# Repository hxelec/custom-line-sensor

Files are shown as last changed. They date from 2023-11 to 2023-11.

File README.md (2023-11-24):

# custom-line-sensor
A simple design for a custom line sensing array, using the well-known QRE1113GR reflective sensor, which is seen in most line followers (including crazy fast PID ones). The same design is also seen in the QTR series from Pololu.
Full tutorial is documented on my YouTube channel: https://www.youtube.com/watch?v=jIgIj2hZbxc
Notes: 
You really only need the QRE1113GR itself, and two resistors, however, I decided to add two decoupling capacitors for more stable signals. That makes the entire project just 18 parts, which is pretty simple.
Also, the tutorial PCB layout isn't the exact same as the one that I actually printed and used, for recording purposes. (It still works the exact same)
Nevertheless, the design files of the one I actually sent off to be manufactured are in this repository.

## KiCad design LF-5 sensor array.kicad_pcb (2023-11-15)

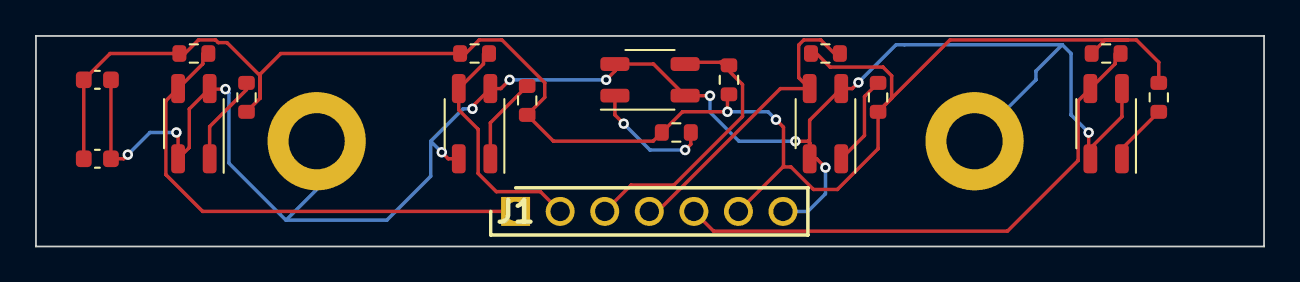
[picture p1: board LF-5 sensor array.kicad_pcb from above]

Board: 2 copper layers, 70.0 x 12.0 mm, 20 parts (0 on the bottom side), 12 nets.

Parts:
C1: 0.1 uF; C_0603_1608Metric
C2: 1 uF; C_0603_1608Metric
H1, H2: M3 hole; MountingHole_3.2mm_M3_DIN965_Pad
J1: Pin Header 7P; HDRV7W64P0X254_1X7_1778X254X869P
R1, R3, R5, R7, R9: 220; R_0603_1608Metric
R2, R4, R6, R8, R10: 47k; R_0603_1608Metric
U1, U2, U3, U4, U5: QRE1113GR; OnSemi_CASE100CY

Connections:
/O1: J1.1, R2.2, U1.3
/O2: J1.2, R4.2, U2.3
/O3: J1.3, R6.2, U3.3
/O4: J1.4, R8.2, U4.3
/O5: J1.5, R10.2, U5.3
GND: C1.2, C2.2, H1.1, H2.1, J1.7, U1.2 (K), U1.4, U2.2 (K), U2.4, U3.2 (K), U3.4, U4.2 (K), U4.4, U5.2 (K), U5.4
unnamed: R1.2, U1.1 (A)
unnamed: R3.2, U2.1 (A)
unnamed: R5.2, U3.1 (A)
unnamed: R7.2, U4.1 (A)
unnamed: R9.2, U5.1 (A)
VCC: C1.1, C2.1, J1.6, R1.1, R2.1, R3.1, R4.1, R5.1, R6.1, R7.1, R8.1, R9.1, R10.1

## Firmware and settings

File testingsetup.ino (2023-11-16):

/*
Hardware:
ESP32-C3 Super Mini
0.96" OLED (I2C)
The line sensor shown in this repository

Connections:
SCL of OLED goes to GPIO4 of ESP32-C3 Super Mini
SDA of OLED goes to GPIO1 of ESP32-C3 Super Mini
GPIO0, 5, 7, 10, 21 goes to Output 1 - 5 of Line Sensor

Functionality:
When one of the outputs of the line sensor is low, a circle will show up in the corresponding position. You can see this in action in my YouTube video linked in README
*/

#include <Arduino.h>
#include <U8g2lib.h>

#ifdef U8X8_HAVE_HW_SPI
#include <SPI.h>
#endif
#ifdef U8X8_HAVE_HW_I2C
#include <Wire.h>
#endif

U8G2_SSD1306_128X64_NONAME_F_SW_I2C u8g2(U8G2_R0, /* clock=*/ 4, /* data=*/ 1, /* reset=*/ U8X8_PIN_NONE);

void setup(void) {
  pinMode(0, INPUT);
  pinMode(5, INPUT);
  pinMode(7, INPUT);
  pinMode(10, INPUT);
  pinMode(21, INPUT);
  u8g2.begin();
}

void loop(void) {
  u8g2.clearBuffer();					// clear the internal memory
  u8g2.setFont(u8g2_font_ncenB08_tr);	// choose a suitable font
  if (digitalRead(0) == 0) {
    u8g2.drawFilledEllipse(21, 32, 5, 5, U8G2_DRAW_ALL);
  }
  if (digitalRead(5) == 0) {
    u8g2.drawFilledEllipse(42, 32, 5, 5, U8G2_DRAW_ALL);
  }
  if (digitalRead(7) == 0) {
    u8g2.drawFilledEllipse(63, 32, 5, 5, U8G2_DRAW_ALL);
  }
  if (digitalRead(10) == 0) {
    u8g2.drawFilledEllipse(84, 32, 5, 5, U8G2_DRAW_ALL);
  }
  if (digitalRead(21) == 0) {
    u8g2.drawFilledEllipse(105, 32, 5, 5, U8G2_DRAW_ALL);
  }
  if (digitalRead(0) == 1 && digitalRead(5) == 1 && digitalRead(7) == 1 && digitalRead(10) == 1 && digitalRead(21) == 1) {
    u8g2.clearDisplay();
  }
  u8g2.sendBuffer();					// transfer internal memory to the display
  delay(100);  
}
